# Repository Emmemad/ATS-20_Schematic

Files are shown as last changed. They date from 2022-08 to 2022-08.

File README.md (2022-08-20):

# Schematic of the ATS-20 radio receiver

## ATS-20

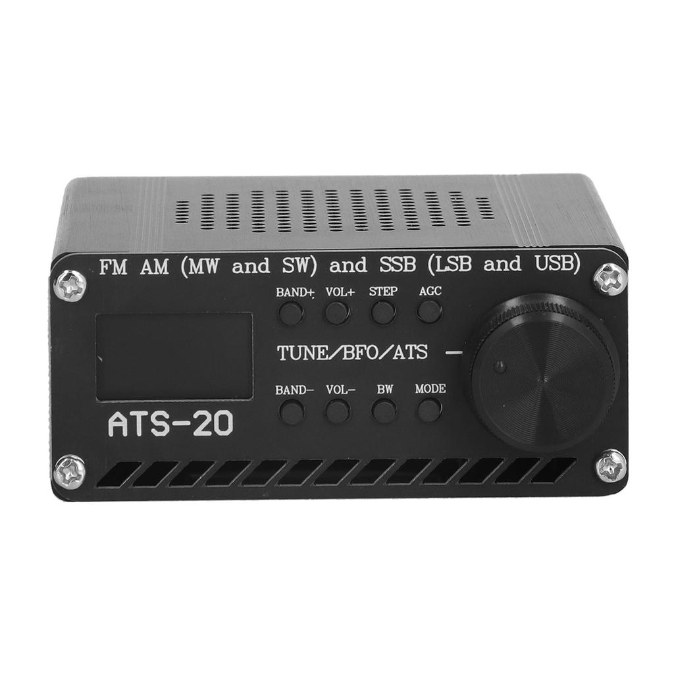
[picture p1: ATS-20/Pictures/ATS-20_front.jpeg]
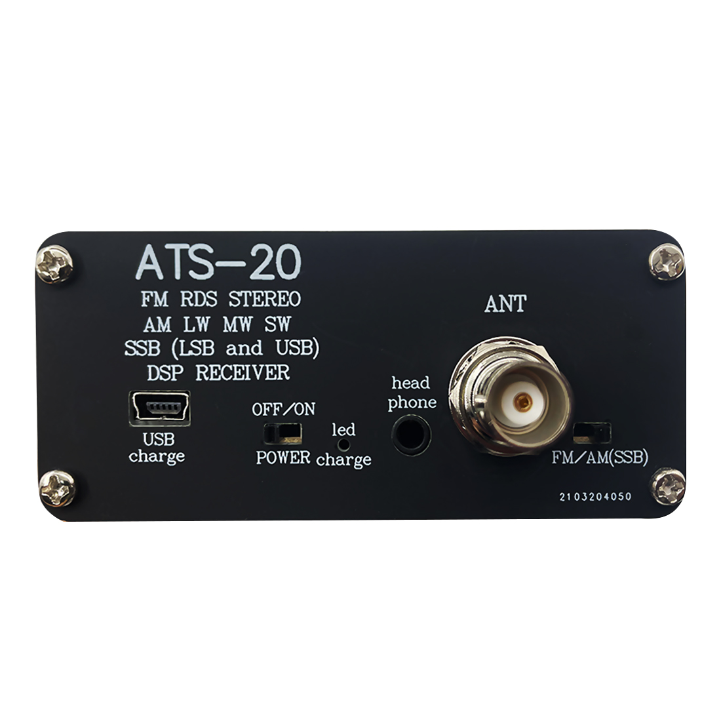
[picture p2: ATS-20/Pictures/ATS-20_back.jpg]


The schematic was traced back from original PCB by TB5CVN published [here](https://www.pcbway.com/project/shareproject/SI4732_SSB_AM_FM_HAM_RADIO.html) and should correspond to products sold as *"ATS-20"* and to some Si4735/Si4732 DIY radio PCB kits.

Values of resistors and some other information was taken from PCB photos by Robert Richmond available [here](https://swling.com/blog/2021/05/si473x-receiver-firmware-update-and-internal-photos/)

Schematic is available as a [KiCAD 6.0 project](/ATS-20/ATS-20_TB5CVN_Trace) and also in [PDF](/ATS-20/ATS-20_Schematic.pdf).

[Pictures](/ATS-20/Pictures) folder contains original and upscaled versions of PCB layout pictures and also other board and unit photos

Unfortunately I do not have the device with me, so if you have one and can correct or add something - feel free to contact me or open an issue

Due to the fact that schematic was traced back from PCB pictures it **may contain errors**, so use this schematic **at your own risk**.

Also be aware that units you buy from chinese sellers can have all sorts of changes in PCB layout and schematics. 

You can get more information about the Si4735/Si4732 radios from PU2CLR's [Github page](https://github.com/pu2clr/SI4735)

## ATS-20+

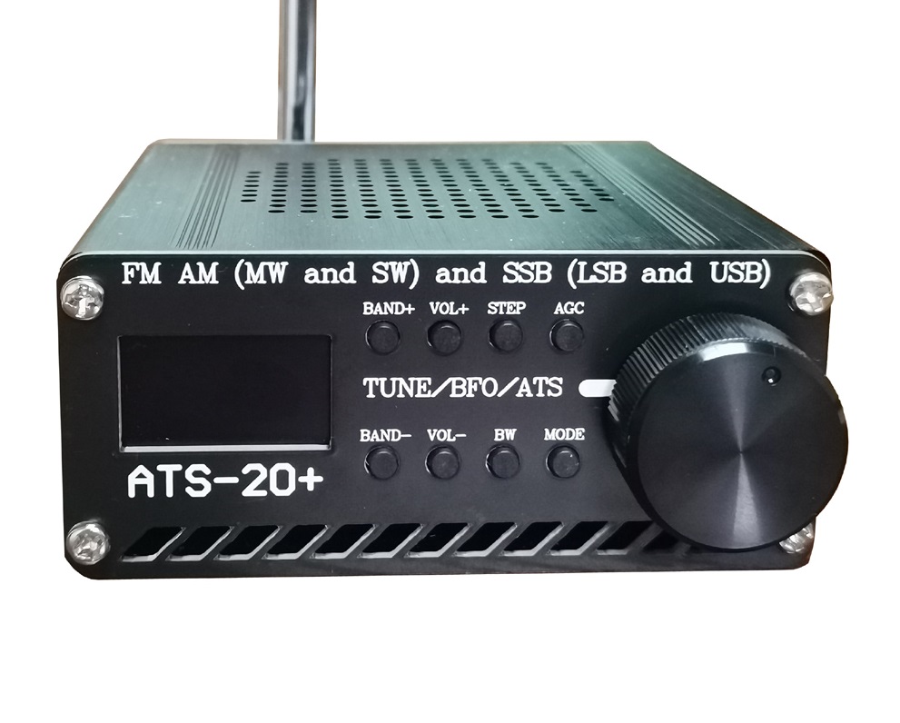
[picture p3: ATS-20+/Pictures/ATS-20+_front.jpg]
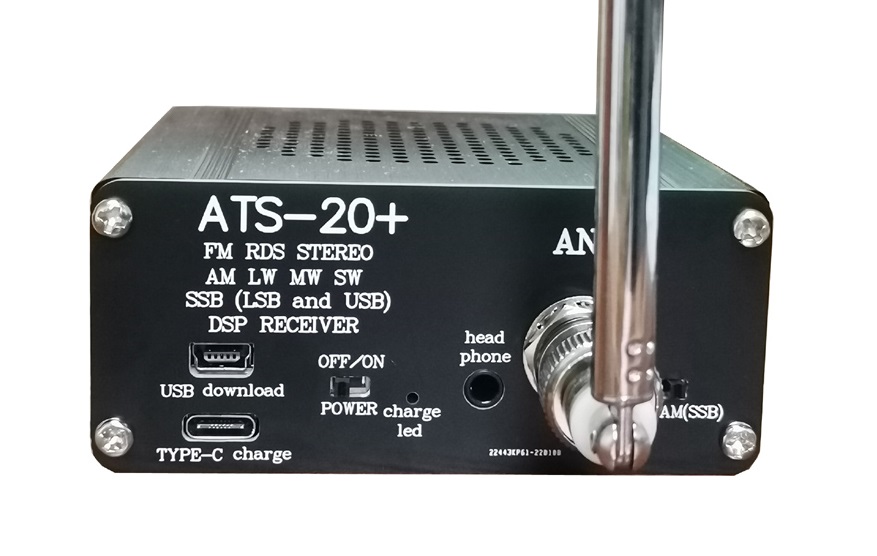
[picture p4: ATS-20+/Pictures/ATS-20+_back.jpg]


ATS-20+ is a newer version of this device with some changes in schematic (most significant change is an addition of the FM filter and amplifier)

Schematic is available as a [KiCAD 6.0 project](/ATS-20/ATS-20_Plus_Trace) and also in [PDF](/ATS-20%2B/ATS-20_Plus_Schematic.pdf).

[Pictures](/ATS-20/Pictures) folder contains PCB and unit photos

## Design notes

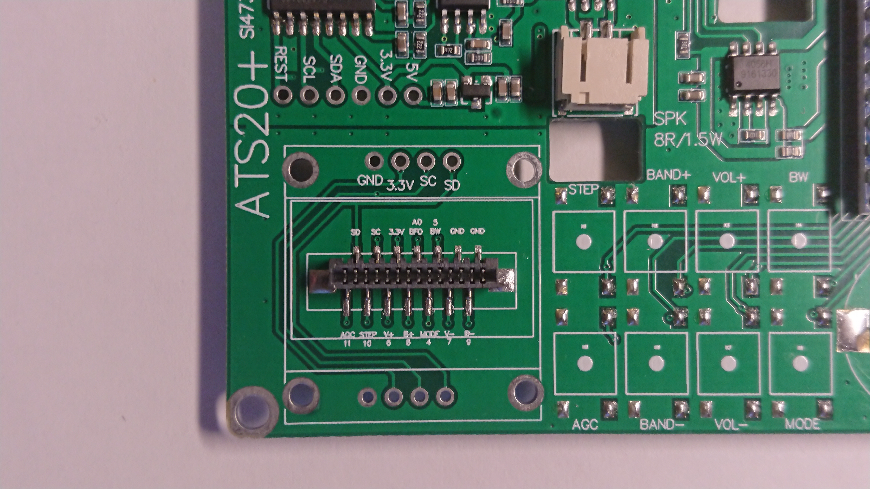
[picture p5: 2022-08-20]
ATS-20+/Pictures/Board_photos/ATS-20_Plus_8.JPG

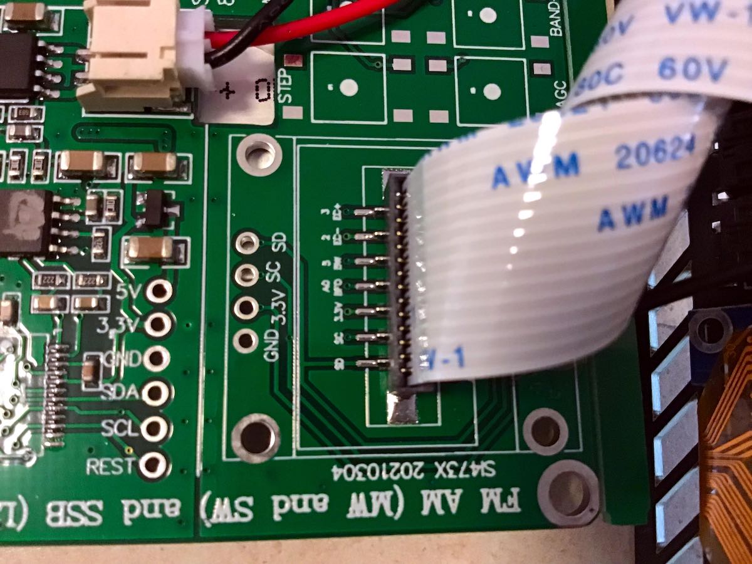
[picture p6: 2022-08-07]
ATS-20/Pictures/Robert Richmond's photos/Si4732-Internal-Photos-Robert-Richmond-7.jpeg

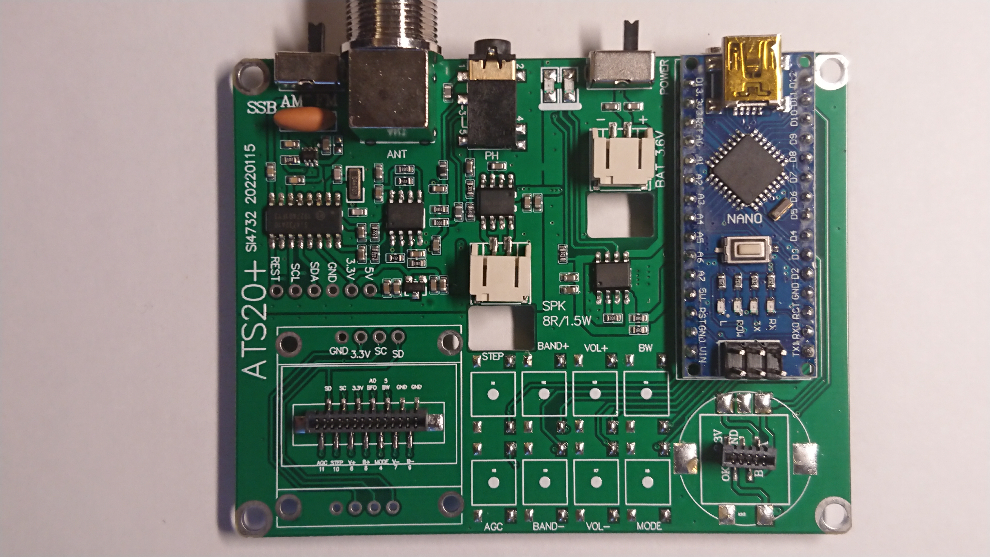
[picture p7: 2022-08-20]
ATS-20+/Pictures/Board_photos/ATS-20_Plus_1.JPG

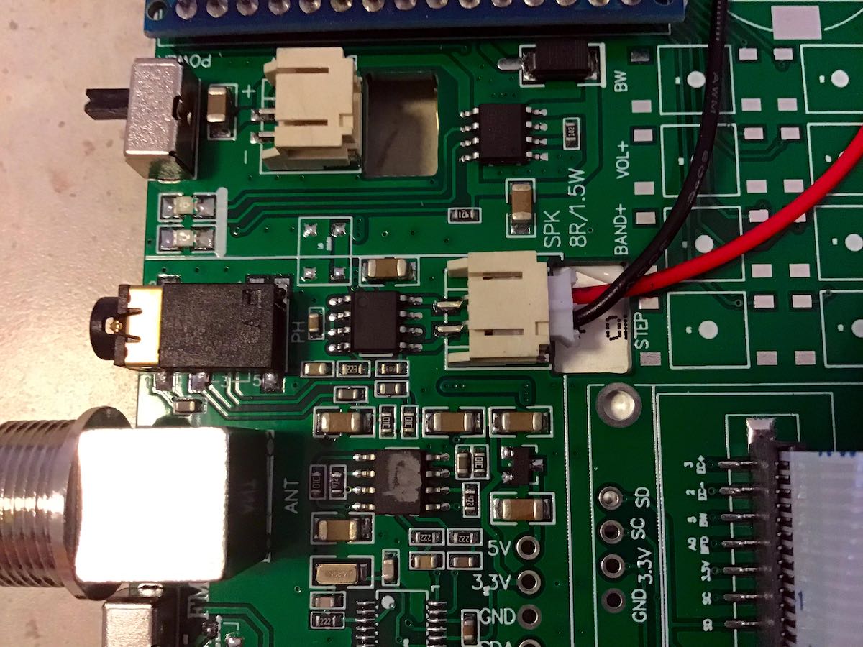
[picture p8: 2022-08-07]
ATS-20/Pictures/Robert Richmond's photos/Si4732-Internal-Photos-Robert-Richmond-3.jpeg

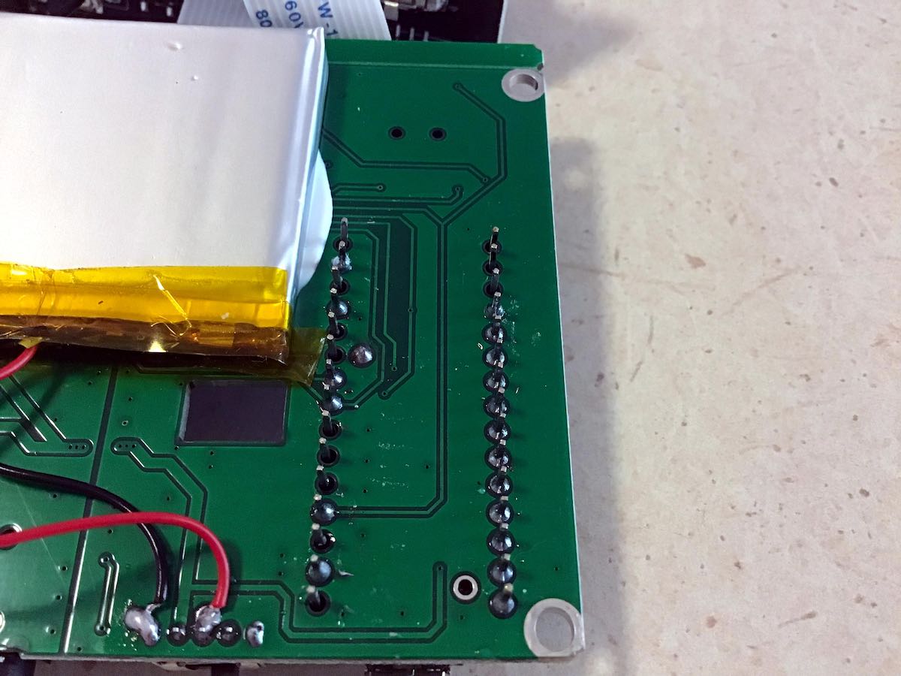
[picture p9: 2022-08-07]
ATS-20/Pictures/Robert Richmond's photos/Si4732-Internal-Photos-Robert-Richmond-11.jpeg

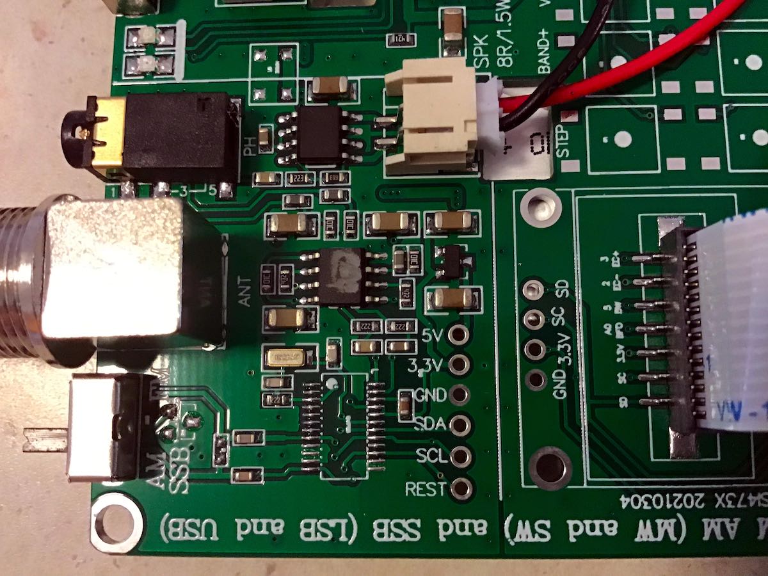
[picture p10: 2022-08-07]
ATS-20/Pictures/Robert Richmond's photos/Si4732-Internal-Photos-Robert-Richmond-4.jpeg

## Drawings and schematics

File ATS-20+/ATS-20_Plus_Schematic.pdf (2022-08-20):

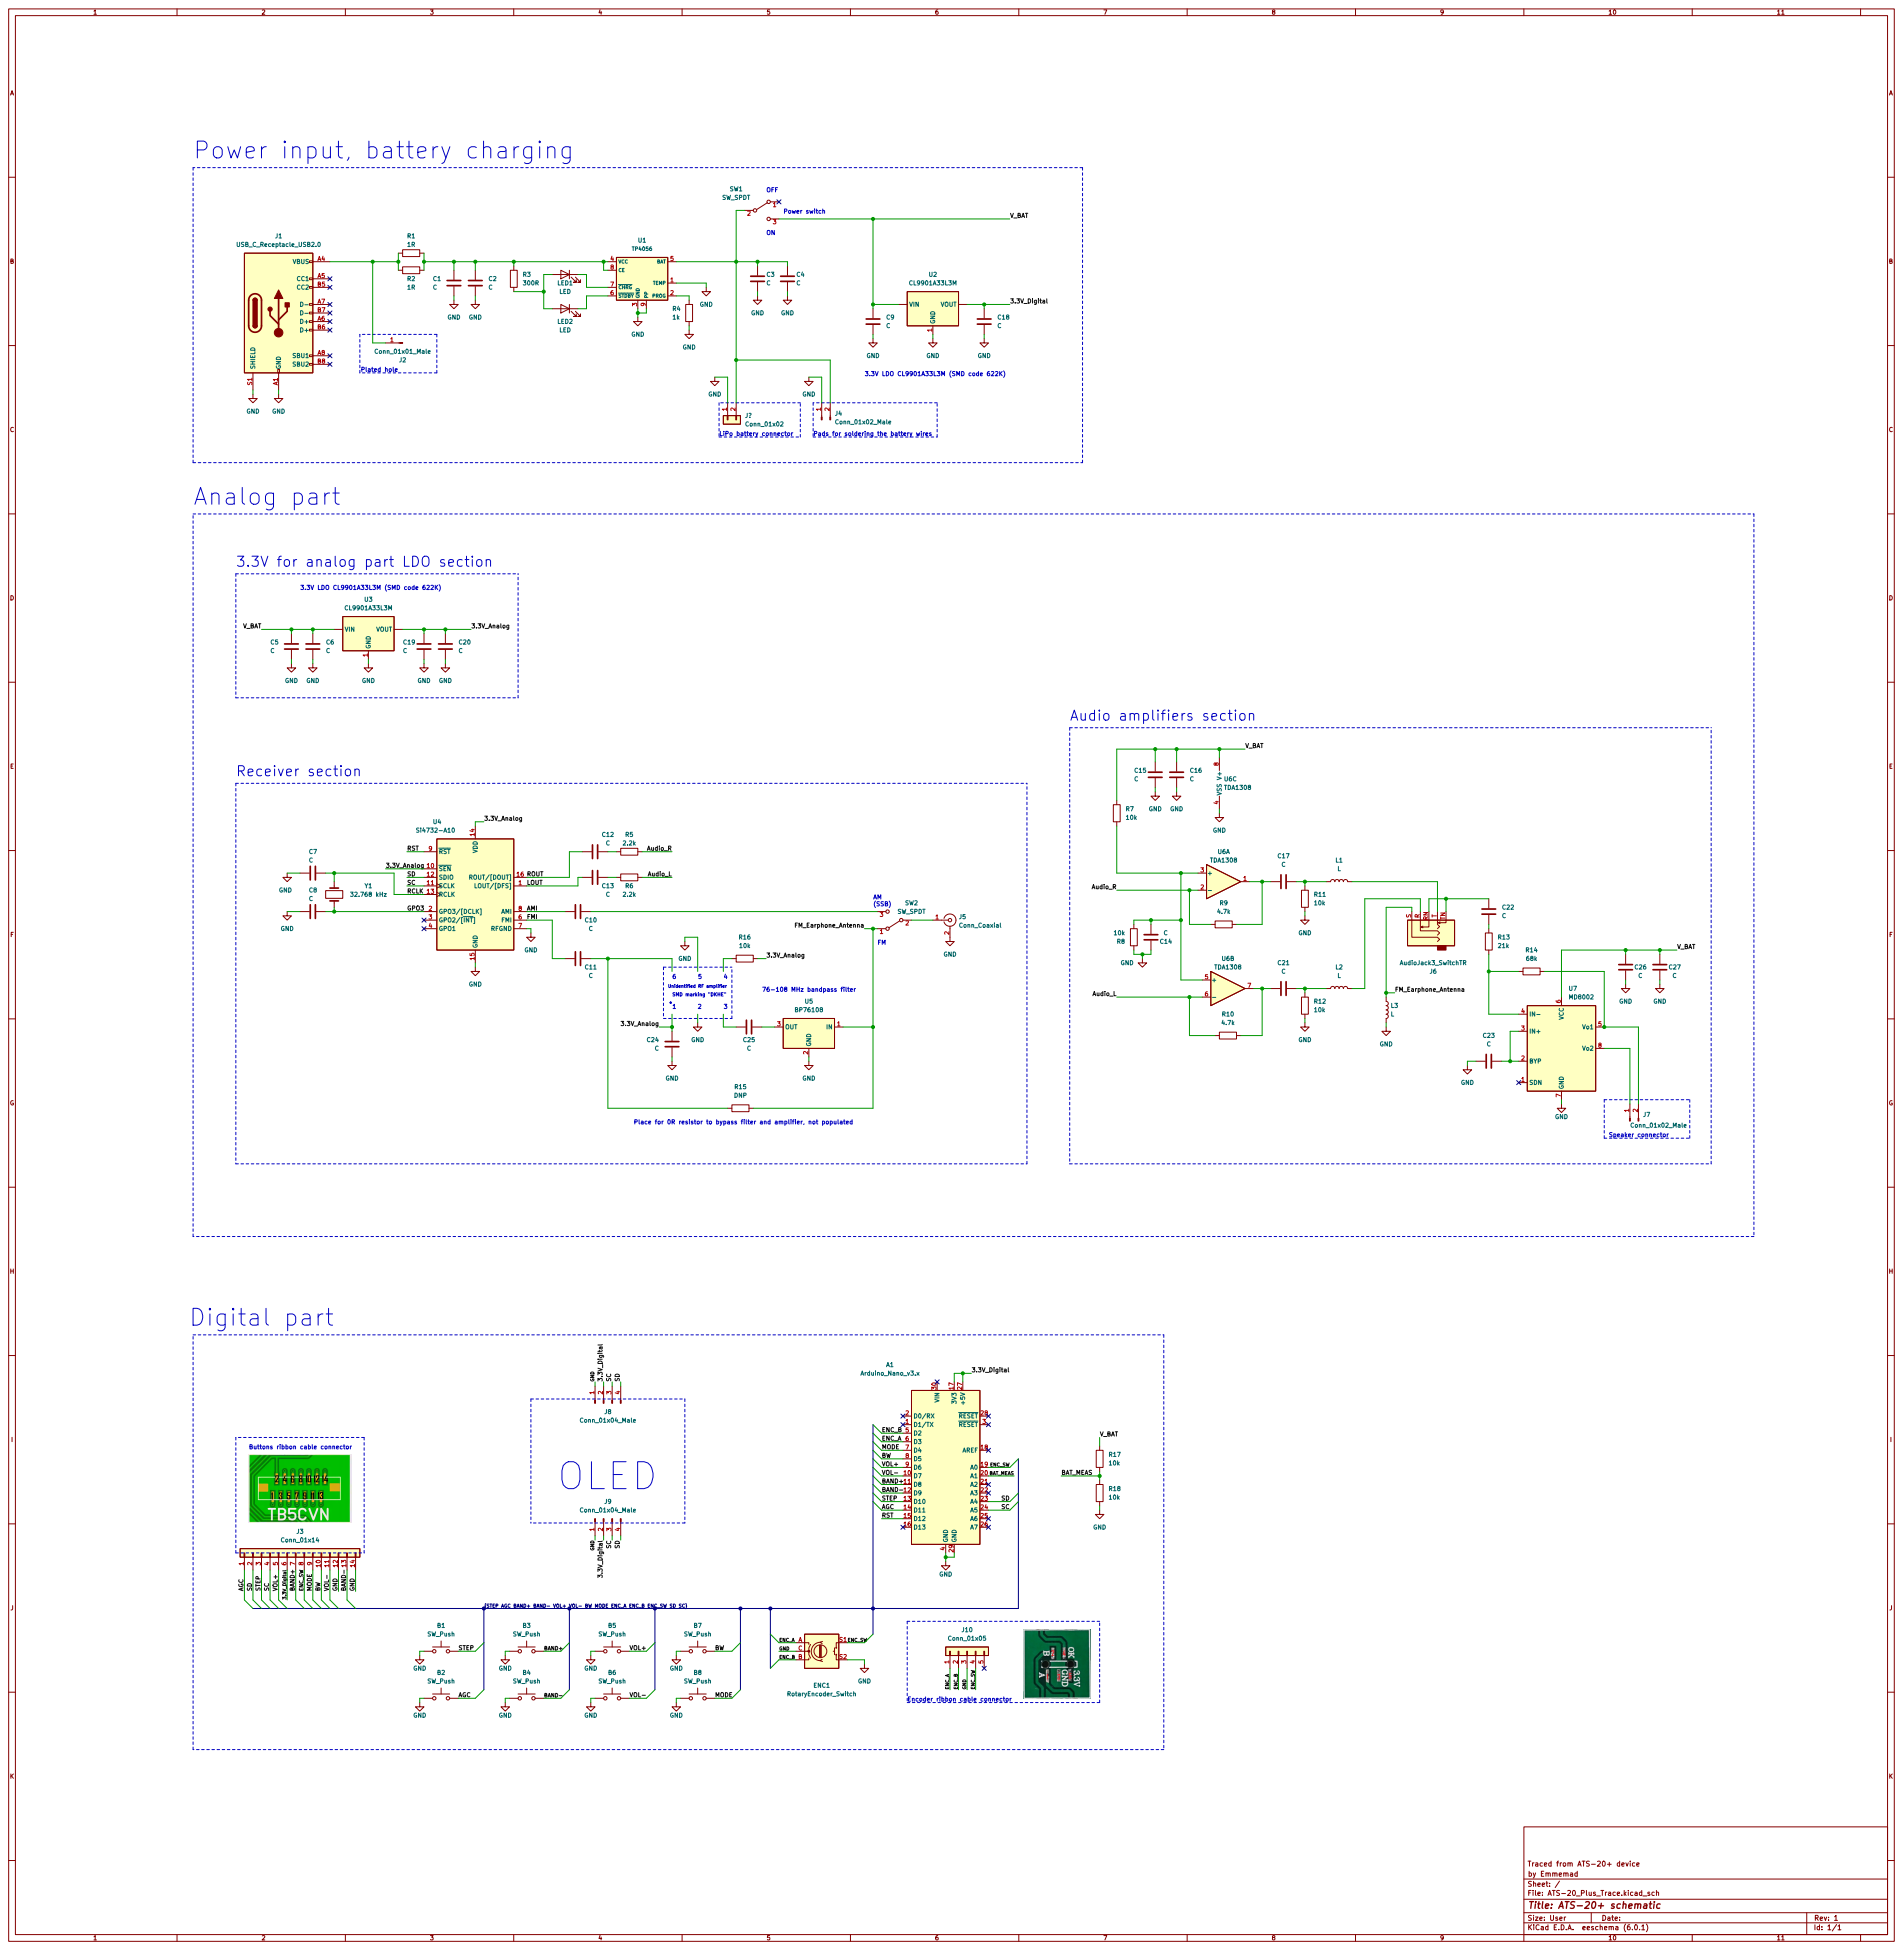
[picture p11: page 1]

Plated hole Power input, battery charging

3.3V LDO CL9901A33L3M (SMD code 622K) Power switch ON

Pads for soldering the battery wires

SMD marking "DKHE" 3 Analog part

3.3V for analog part LDO section

Place for 0R resistor to bypass filter and amplifier, not populated

Encoder ribbon cable connector Buttons ribbon cable connector

Traced from ATS-20+ device
File: ATS-20_Plus_Trace.kicad_sch Sheet: / by Emmemad

Id: 1/1 Title: ATS-20+ schematic

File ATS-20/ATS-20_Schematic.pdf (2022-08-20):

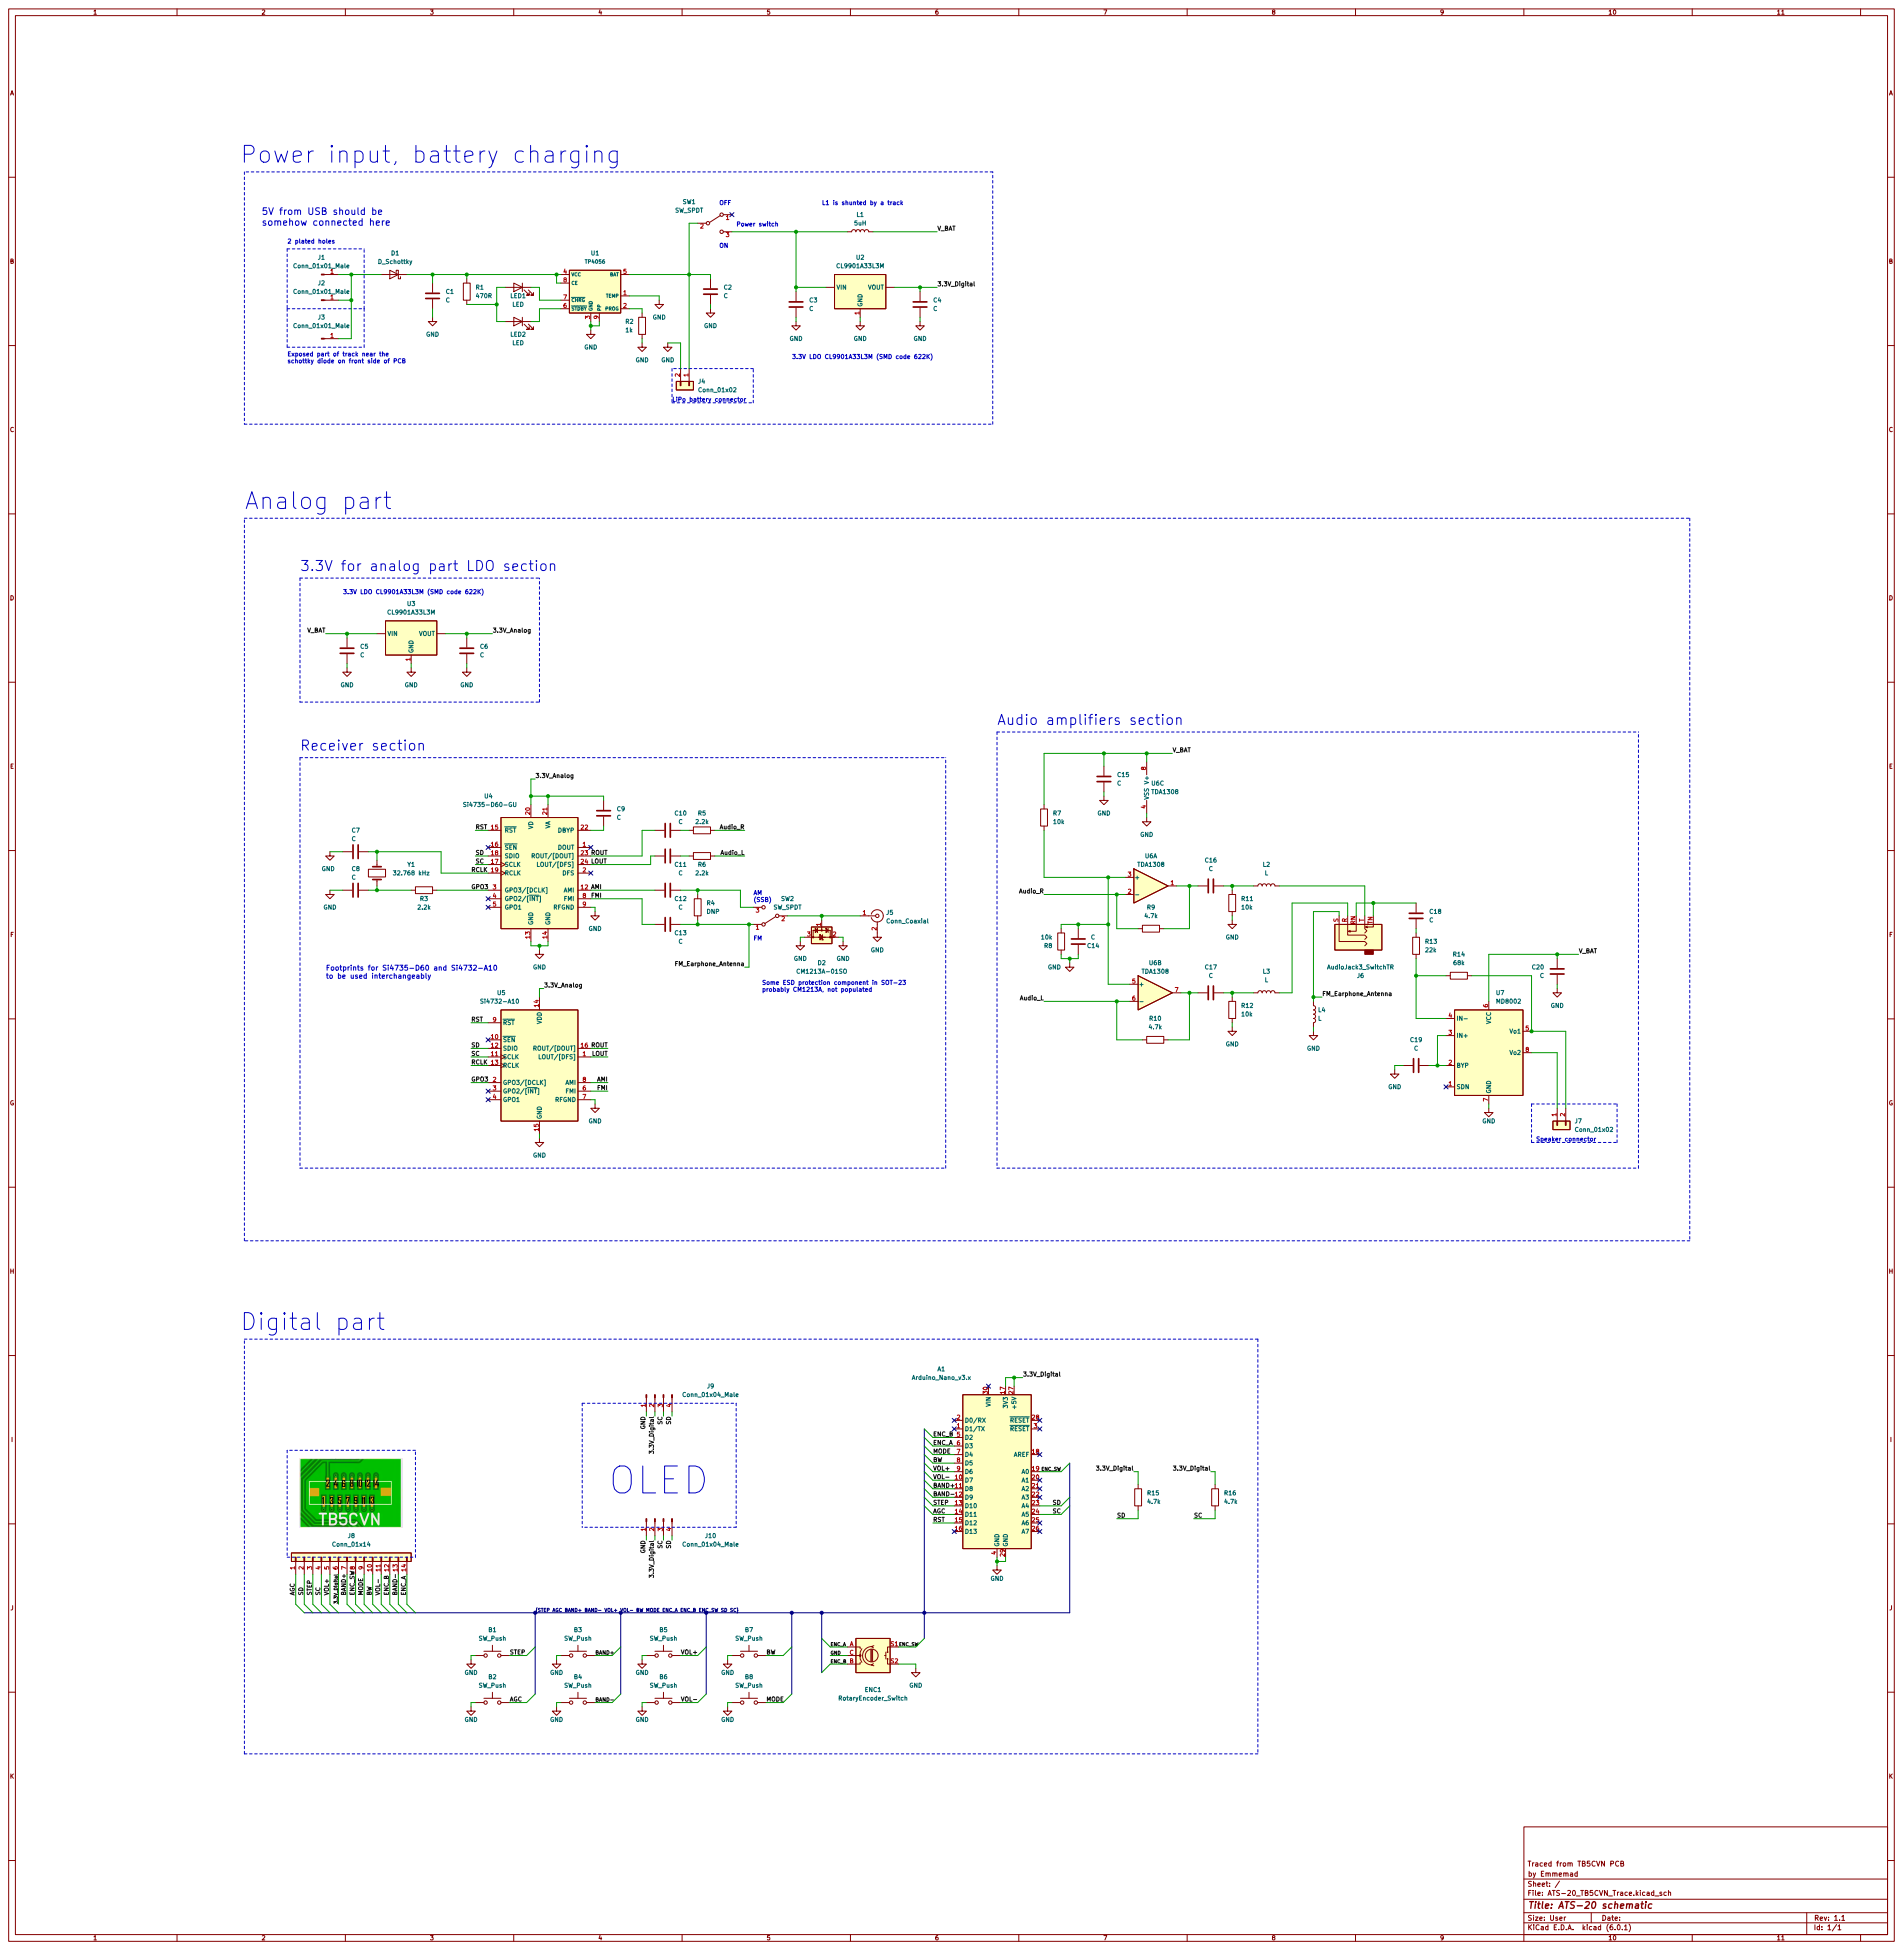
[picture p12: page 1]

Power input, battery charging

5V from USB should be
somehow connected here

Power switch OFF Receiver section

L1 is shunted by a track ON

Exposed part of track near the
schottky diode on front side of PCB

3.3V for analog part LDO section

Footprints for Si4735-D60 and Si4732-A10
to be used interchangeably

Some ESD protection component in SOT-23
probably CM1213A, not populated

Traced from TB5CVN PCB
File: ATS-20_TB5CVN_Trace.kicad_sch Sheet: / by Emmemad

Id: 1/1 Title: ATS-20 schematic

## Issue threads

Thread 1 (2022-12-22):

Device Marking of the "Unidentified RF amplifier"...

dl9sec, 2022-12-22:
Hi,

yesterday I got an ATS-20+ from Amazon (brand "Yunxwd").
The RF amps device marking here is "C1R". This could be a UPC2746TB from HUABAN (formerly this amp was from NEC).
The pinning seems to be turned by 180° and there is a little discrepancy at the connections:
The VCC pin of the "DKHE" is marked as "GND" at the "C1R" and the pin which seems to be some bias (with the series 10k resistor) at the "DKHE" is marked as VCC at the "C1R".
So either this isn't a UPC2746TB or it works by chance...

Regards, Thorsten

m4rc0d1, 2024-02-28:
I also have one unit with the RF amplifier marked "C1R" and this seems to be a uPC2746TB from CEL or other manufacturers. Looking at the datasheet (https://www.mouser.it/datasheet/2/286/upc2745tb-36504.pdf or https://www.renesas.com/us/en/document/dst/upc2745tbupc2746tb-ds-pu10443ej01v0ds) the pins seem arranged in a different way than the "usual". Looking at the marking in a natural reading orientation, pin 1 is top-left and then the numbers go up in a clockwise direction (C1Q and C1R are the same chip with different gain and NF):

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

The pin numbering is standard when looking at the package from the bottom, something impossible with the chip soldered on the board.

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
This makes sense looking at the datasheet's pins list:
```
1 INPUT
2 GND
3 GND
4 OUTPUT
5 GND
6 VCC
```
The only strange connection is at pin 3 that the datasheet specifies as GND, but in the circuit it is connected to 3.3V, with a bypass cap to ground. Looking at the internal connections pin 3 is not directly connected to pins 2, 5 and the only reason I can think to do this is to reduce the overall gain of the amp and not saturate the receiver with the strong FM signal, but I haven't tested that.

According to these info, the schematic could be modified in the following way:

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

vatonek, 2025-05-14:
So here is the RF part schematics:

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

vatonek, 2025-05-15:
Here is translated datasheet page #3 (description in chinese language):

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

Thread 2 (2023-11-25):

USB-PD

moriel5, 2023-11-25:
It's not entirely clear, however looking at the pictures of the ATS-20 Plus, I can see two resistors near the USB-C port.

Would this indicate that it is compliant with the USB-C specification, and as such should work with USB-PD chargers (albeit at 5V only, since I do not see any dedicated USB-PD components that would step it up higher)?

Also, I am currently searching for an battery housing adapter for 18650 cells (very useful for having replaceable batteries, though would likely require protected cells) Should I find something, I shall post it here.

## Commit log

2022-08-07 Initial file upload
    [ATS-20_TB5CVN_Trace.kicad_pcb, ATS-20_TB5CVN_Trace.kicad_sch]
2022-08-20 Some schematic corrections
    Changed incorrectly identified components in audio section - inductors (ferrite beads maybe?) is now shown instead of capacitors
    [ATS-20_TB5CVN_Trace.kicad_sch]
2022-08-20 ATS-20+ schematic added
    [ATS-20_Plus_Trace.kicad_pcb, ATS-20_Plus_Trace.kicad_sch]
2022-08-20 Added ATS-20+ board photos
2022-08-20 Added info about ATS-20+ schematic
